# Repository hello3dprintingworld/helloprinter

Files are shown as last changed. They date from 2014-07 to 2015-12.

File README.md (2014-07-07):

helloprinter
============

Open Source Multi-Maker (3D printer, CNC, Laser cutter/engraver)

Based on the work of josef prusa, model prusa I3 link: https://github.com/josefprusa/Prusa3

Base model characteristics:

Build Size: 200mm x 200mm x 200mm
Resolution: Base nozzle has 3 diferent resolutions 0,2 , 0,3 and 0,5, if you choose the chess extruder you can go as high as 2mm, ideal for the bigger versions.
Z Resolution: Best achieved with a normal calbration 0,1mm , when well calibrated you can reach resolutions of 0,01mm
Materials: ABS, ABS-PC,ABS-Carborn, Glow In The Dark ABS and PLA, PLA, HIPS, Laywoo, Claywoo, Nylon, PVA and others
Speed: Up to 100mm/s (tested with 2000mm/s set up and worked)
Prepared for automatic bed levelling
Monkey Extruder - Super lightweight Dual extruder ( motors with half the weight of a nema 17) with the capability of separating both nozzles up to half the bed lenght, making possible the print of 2 objects in diferent materials or colors at the same time saving 50% of the building time for not having to do the same path twice.
The filament is visible all the way to the nozzle, making easy to do mantaince and cleaning
Stainless Steel Structure - Needed for having enough weight to withstand the CNC function
Magnétic Sensors for precise home positionning
Ramps 1.4 and Arduino Mega 2650 - 5 motor drivers (dual Z Driver and Dual Extruder), 3 12v exits for FAN, BED and EXTRUDER combinations and support for 4 servos.
LCD with SD card reader for Autonomouse print
Print speed control during print
Marlin Firmware

Software recomended
Kisslicer or Slic3r and pronterface

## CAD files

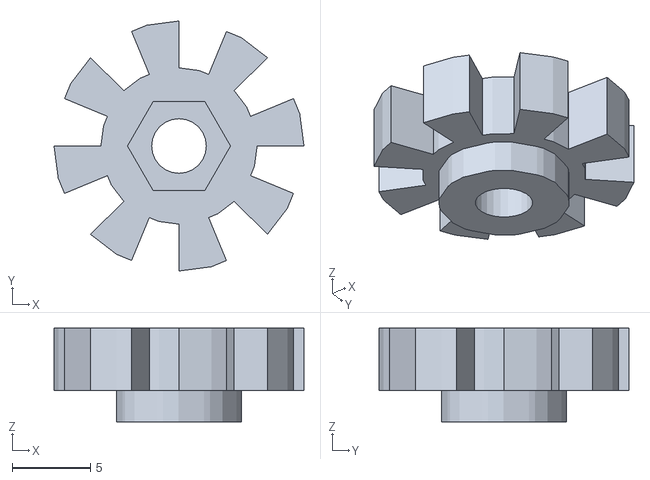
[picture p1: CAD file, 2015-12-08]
Bed/Bed Adjuster.stl
16.0 x 16.0 x 6.00

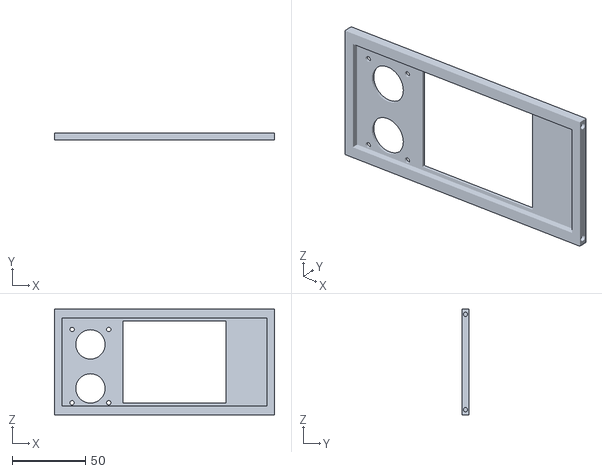
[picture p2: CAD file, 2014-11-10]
Controllers/RAMPS 14/RAMPS BACK 1X.stl
150.0 x 5.00 x 72.0

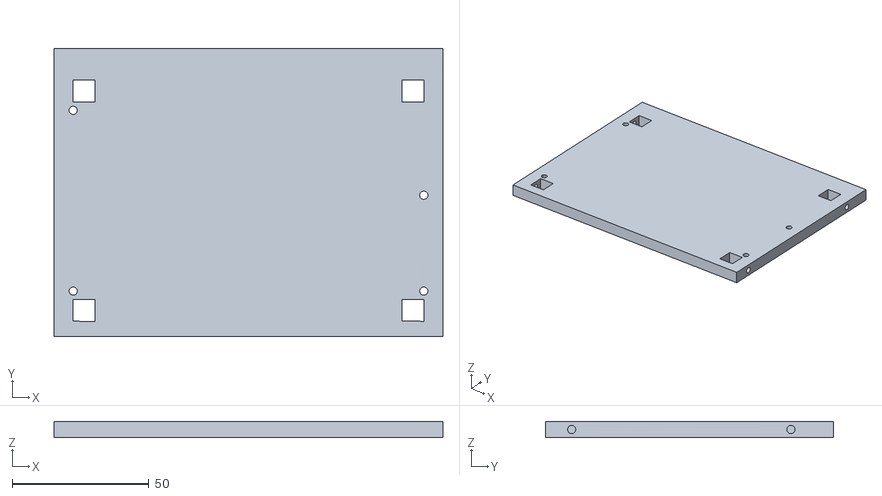
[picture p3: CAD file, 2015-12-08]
Controllers/RUMBA/Power Box Rumba BOT.stl
142.0 x 105.0 x 6.00

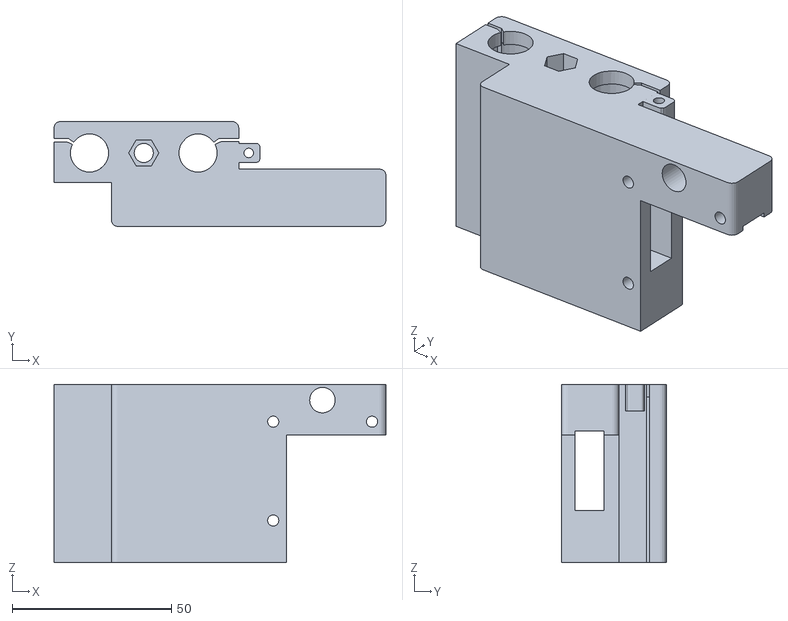
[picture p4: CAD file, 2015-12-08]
Eixo X/5mm/x axis motor.stl
104.2 x 32.9 x 56.0

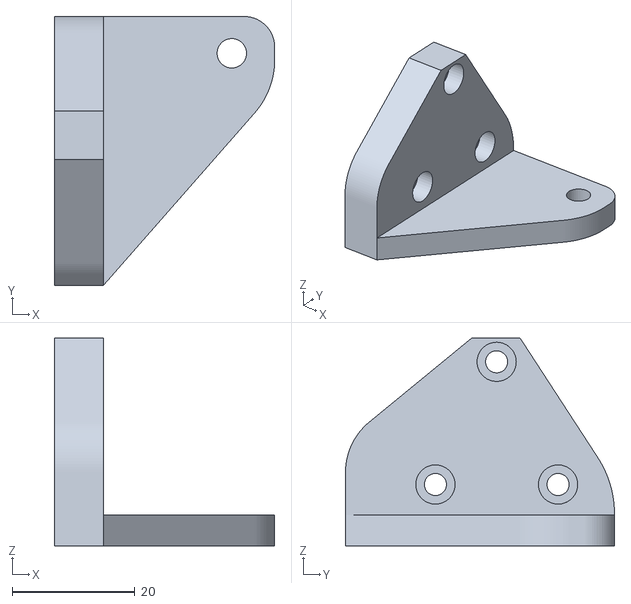
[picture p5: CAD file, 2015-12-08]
Eixo Y/Y idler 2.stl
35.9 x 43.9 x 33.9

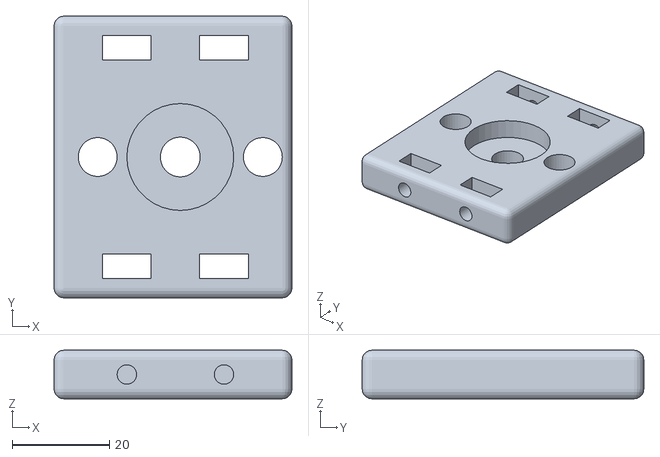
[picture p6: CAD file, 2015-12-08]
Eixo Z/Z Top x2.stl
49.0 x 58.0 x 10.0

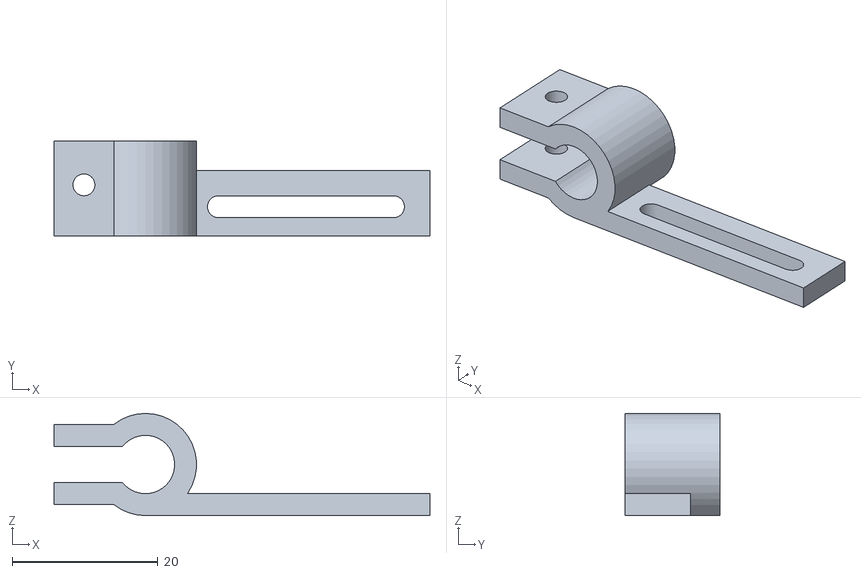
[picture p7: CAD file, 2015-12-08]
Endstops/Universal Endstop holder.STL
51.5 x 13.0 x 14.0

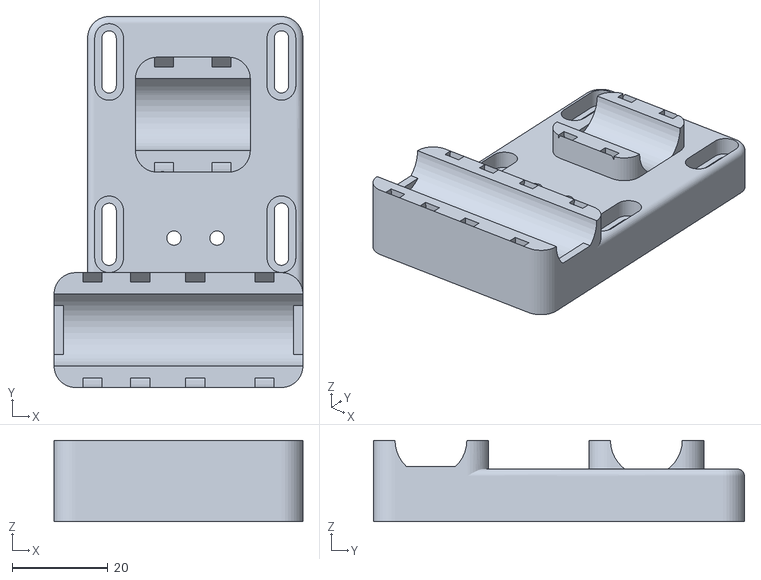
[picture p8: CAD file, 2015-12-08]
Extruder/Single Extruder for dual mirror parts/X Carriage.stl
52.0 x 77.5 x 17.0

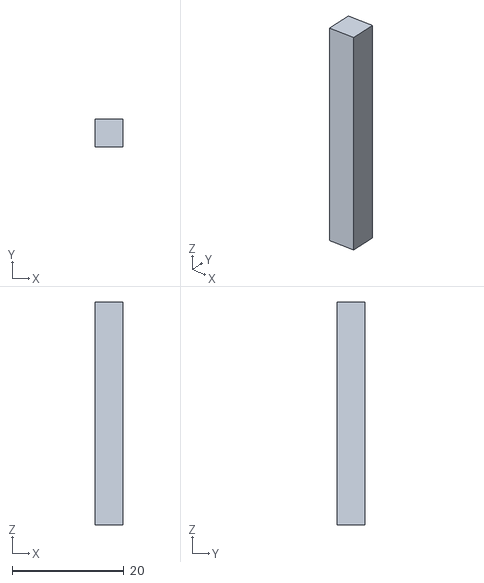
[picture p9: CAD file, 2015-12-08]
Impressão Teste/torre40mm.stl
5.00 x 5.00 x 40.0

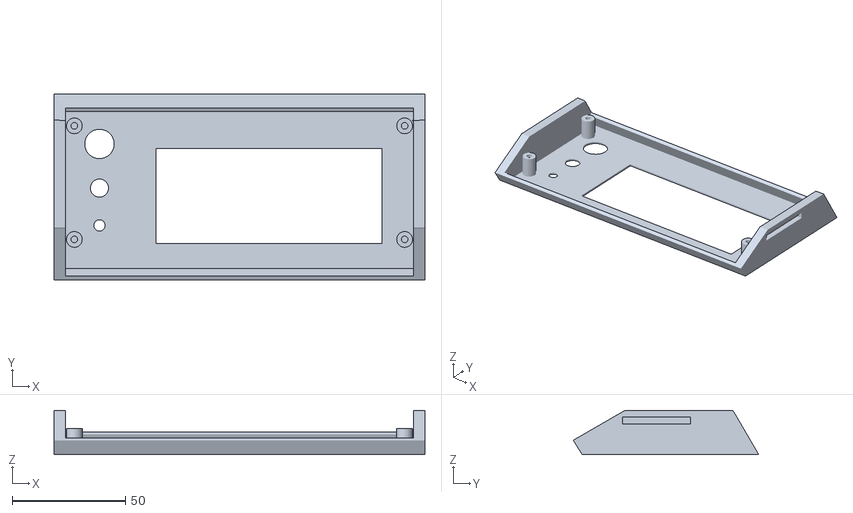
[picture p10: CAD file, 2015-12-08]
LCD/LCD_Mount.stl
164.0 x 82.0 x 19.5

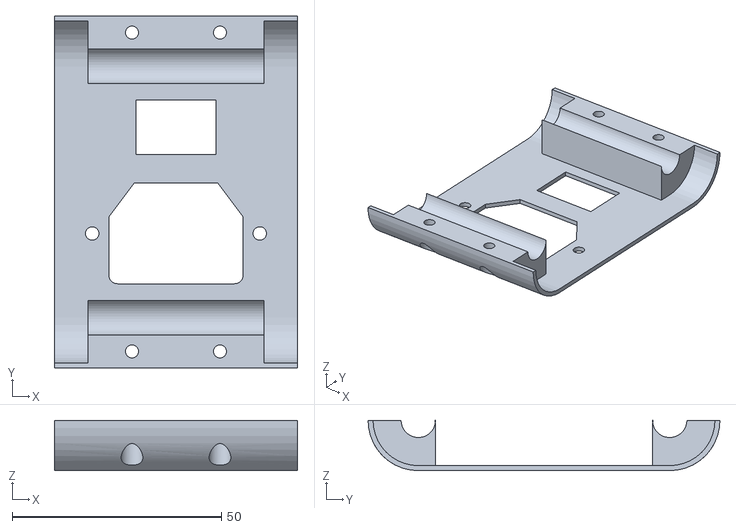
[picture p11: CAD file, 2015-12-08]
Plug and switch/Plug and switch front x1.STL
58.0 x 84.0 x 12.0

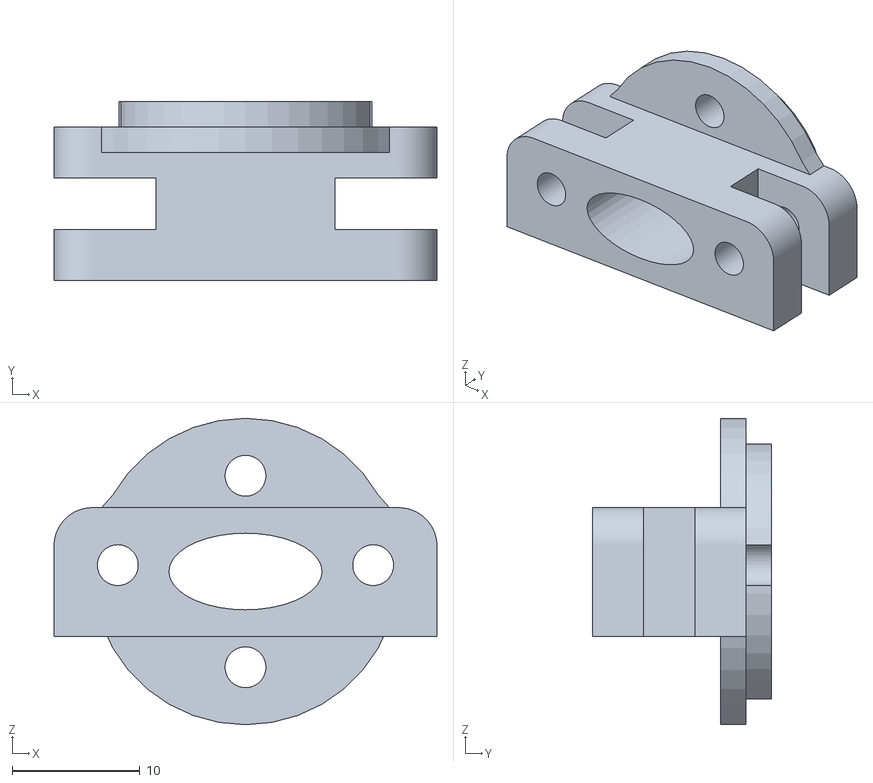
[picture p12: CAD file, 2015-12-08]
Power Supply/Frame cable connection front.stl
30.0 x 14.0 x 24.0

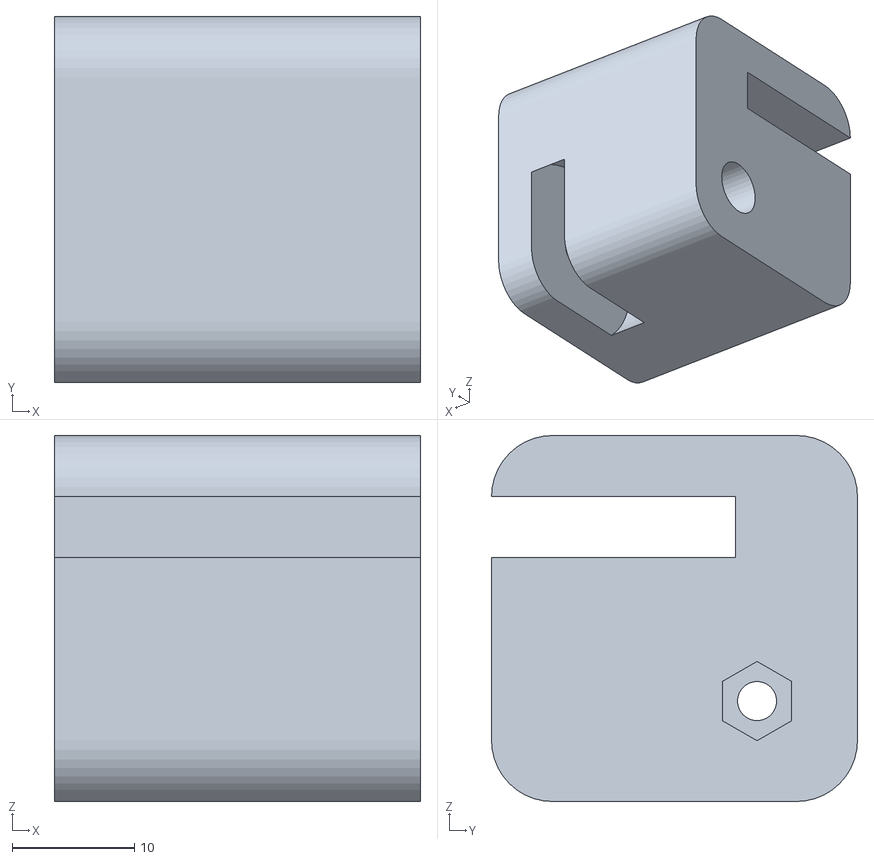
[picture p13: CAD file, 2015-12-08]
Reinforcement XL/Base.STL
30.0 x 30.0 x 30.0

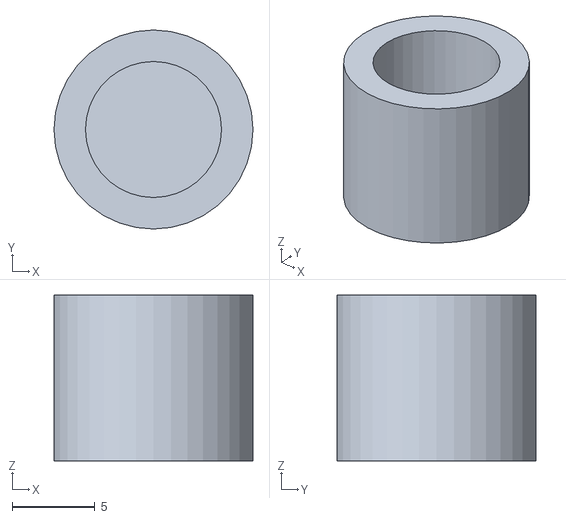
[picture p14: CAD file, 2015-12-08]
Spool Holder/Pointer.stl
12.0 x 12.0 x 10.0

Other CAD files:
Frame/frames.dwg
Bed/Bed Corner Extruder x2.stl
Controllers/RAMPS 14/RAMPS FRONT.stl
Controllers/RUMBA/Power Box Rumba Closed.stl
Bed/Bed corners normal x2.stl
Bed/i3_Adj_Y_Low_P_holder_02.stl
Controllers/RAMPS 14/RAMPS BOTTOM 1X.stl
Controllers/RAMPS 14/RAMPS LAT1.stl
Controllers/RAMPS 14/RAMPS LAT2.stl
Controllers/RAMPS 14/RAMPS TOP.stl
Controllers/RUMBA/LCD back.stl
Controllers/RUMBA/Power Box Rumba FRONT 2.stl
Controllers/RUMBA/Power Box Rumba LAT1.stl
Controllers/RUMBA/Power Box Rumba LAT2.stl
Controllers/RUMBA/Power Box Rumba Support.stl
Controllers/RUMBA/Power Box Rumba TOP.stl
Eixo X/5mm/x axis idler tensioner.stl
Eixo X/5mm/x axis idler.stl
Eixo Y/Y Idler 1.stl
Eixo Y/Y Motor.stl
Eixo Z/Z motor x2.stl
Endstops/endstop-holder-bottom x3.stl
Endstops/endstop-holder-top x3.stl
Extruder/Single Extruder for dual mirror parts/extruder - 1-50F.STL
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

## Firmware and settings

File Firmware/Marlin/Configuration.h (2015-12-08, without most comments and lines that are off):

#include <U8glib.h>
#define CONFIGURATION_H
#include "boards.h"
#define STRING_VERSION "1.0.2"
#define STRING_URL "reprap.org"
#define STRING_VERSION_CONFIG_H __DATE__ " " __TIME__ // build date and time
#define STRING_CONFIG_H_AUTHOR "(none, default config)" // Who made the changes.
#define STRING_SPLASH_LINE1 "v" STRING_VERSION // will be shown during bootup in line 1
#define SERIAL_PORT 0
#define BAUDRATE 250000
#define MOTHERBOARD 80
 #define CUSTOM_MENDEL_NAME "HelloPrinter"
#define EXTRUDERS 2
#define POWER_SUPPLY 1
#define TEMP_SENSOR_0 1
#define TEMP_SENSOR_1 1
#define TEMP_SENSOR_2 0
#define TEMP_SENSOR_3 0
#define TEMP_SENSOR_BED 1
#define MAX_REDUNDANT_TEMP_SENSOR_DIFF 10
#define TEMP_RESIDENCY_TIME 10  // (seconds)
#define TEMP_HYSTERESIS 3       // (degC) range of +/- temperatures considered "close" to the target one
#define TEMP_WINDOW     1       // (degC) Window around target to start the residency timer x degC early.
#define HEATER_0_MINTEMP 5
#define HEATER_1_MINTEMP 5
#define HEATER_2_MINTEMP 5
#define HEATER_3_MINTEMP 5
#define BED_MINTEMP 5
#define HEATER_0_MAXTEMP 275
#define HEATER_1_MAXTEMP 275
#define HEATER_2_MAXTEMP 275
#define HEATER_3_MAXTEMP 275
#define BED_MAXTEMP 150
#define PIDTEMP
#define BANG_MAX 255 // limits current to nozzle while in bang-bang mode; 255=full current
#define PID_MAX BANG_MAX // limits current to nozzle while PID is active (see PID_FUNCTIONAL_RANGE below); 255=full current
  #define PID_FUNCTIONAL_RANGE 10 // If the temperature difference between the target temperature and the actual temperature
  #define PID_INTEGRAL_DRIVE_MAX PID_MAX  //limit for the integral term
  #define K1 0.95 //smoothing factor within the PID
    #define  DEFAULT_Kp 22.2
    #define  DEFAULT_Ki 1.08
    #define  DEFAULT_Kd 114
#define MAX_BED_POWER 255 // limits duty cycle to bed; 255=full current
#define PREVENT_DANGEROUS_EXTRUDE
#define PREVENT_LENGTHY_EXTRUDE
#define EXTRUDE_MINTEMP 170
#define EXTRUDE_MAXLENGTH (X_MAX_LENGTH+Y_MAX_LENGTH) //prevent extrusion of very large distances.
#define THERMAL_RUNAWAY_PROTECTION_PERIOD 10 //in seconds
#define THERMAL_RUNAWAY_PROTECTION_HYSTERESIS 25 // in degree Celsius
#define THERMAL_RUNAWAY_PROTECTION_BED_PERIOD 10 //in seconds
#define THERMAL_RUNAWAY_PROTECTION_BED_HYSTERESIS 10 // in degree Celsius
#define ENDSTOPPULLUPS // Comment this out (using // at the start of the line) to disable the endstop pullup resistors
const bool X_MIN_ENDSTOP_INVERTING = false; // set to true to invert the logic of the endstop.
const bool Y_MIN_ENDSTOP_INVERTING = false; // set to true to invert the logic of the endstop.
const bool Z_MIN_ENDSTOP_INVERTING = false; // set to true to invert the logic of the endstop.
const bool X_MAX_ENDSTOP_INVERTING = false; // set to true to invert the logic of the endstop.
const bool Y_MAX_ENDSTOP_INVERTING = false; // set to true to invert the logic of the endstop.
const bool Z_MAX_ENDSTOP_INVERTING = false; // set to true to invert the logic of the endstop.
#define X_ENABLE_ON 0
#define Y_ENABLE_ON 0
#define Z_ENABLE_ON 0
#define E_ENABLE_ON 0 // For all extruders
#define DISABLE_X false
#define DISABLE_Y false
#define DISABLE_Z false
#define DISABLE_E false // For all extruders
#define DISABLE_INACTIVE_EXTRUDER true //disable only inactive extruders and keep active extruder enabled
#define INVERT_X_DIR false
#define INVERT_Y_DIR false
#define INVERT_Z_DIR false
#define INVERT_E0_DIR false
#define INVERT_E1_DIR false
#define INVERT_E2_DIR false
#define INVERT_E3_DIR false
#define X_HOME_DIR -1
#define Y_HOME_DIR -1
#define Z_HOME_DIR -1
#define min_software_endstops true // If true, axis won't move to coordinates less than HOME_POS.
#define max_software_endstops true  // If true, axis won't move to coordinates greater than the defined lengths below.
#define X_MIN_POS 0
#define Y_MIN_POS 0
#define Z_MIN_POS 0
#define X_MAX_POS 200
#define Y_MAX_POS 200
#define Z_MAX_POS 500
#define Z_PROBE_REPEATABILITY_TEST  // If not commented out, Z-Probe Repeatability test will be included if Auto Bed Leveling is Enabled.
#define NUM_AXIS 4 // The axis order in all axis related arrays is X, Y, Z, E
#define HOMING_FEEDRATE {50*60, 50*60, 4*60, 0}  // set the homing speeds (mm/min)
#define DEFAULT_AXIS_STEPS_PER_UNIT   {80,80,4000,1100}  // default steps per unit for Ultimaker
#define DEFAULT_MAX_FEEDRATE          {300, 300, 5, 45}    // (mm/sec)
#define DEFAULT_MAX_ACCELERATION      {1200,1200,100,300}    // X, Y, Z, E maximum start speed for accelerated moves. E default values are good for Skeinforge 40+, for older versions raise them a lot.
#define DEFAULT_ACCELERATION          250    // X, Y, Z and E acceleration in mm/s^2 for printing moves
#define DEFAULT_RETRACT_ACCELERATION  300   // E acceleration in mm/s^2 for retracts
#define DEFAULT_TRAVEL_ACCELERATION   1200    // X, Y, Z acceleration in mm/s^2 for travel (non printing) moves
#define DEFAULT_XYJERK                20.0    // (mm/sec)
#define DEFAULT_ZJERK                 0.4     // (mm/sec)
#define DEFAULT_EJERK                 2.0    // (mm/sec)
#define CUSTOM_M_CODES
#define PLA_PREHEAT_HOTEND_TEMP 180
#define PLA_PREHEAT_HPB_TEMP 70
#define PLA_PREHEAT_FAN_SPEED 0   // Insert Value between 0 and 255
#define ABS_PREHEAT_HOTEND_TEMP 240
#define ABS_PREHEAT_HPB_TEMP 110
#define ABS_PREHEAT_FAN_SPEED 0   // Insert Value between 0 and 255
#define LANGUAGE_INCLUDE GENERATE_LANGUAGE_INCLUDE(en)
  #define DISPLAY_CHARSET_HD44780_JAPAN        // this is the most common hardware
#define REPRAP_DISCOUNT_SMART_CONTROLLER
#define SOFT_PWM_SCALE 0
#define FILAMENT_SENSOR_EXTRUDER_NUM	0  //The number of the extruder that has the filament sensor (0,1,2)
#define MEASUREMENT_DELAY_CM			14  //measurement delay in cm.  This is the distance from filament sensor to middle of barrel
#define DEFAULT_NOMINAL_FILAMENT_DIA  3.0  //Enter the diameter (in mm) of the filament generally used (3.0 mm or 1.75 mm) - this is then used in the slicer software.  Used for sensor reading validation
#define MEASURED_UPPER_LIMIT          3.30  //upper limit factor used for sensor reading validation in mm
#define MEASURED_LOWER_LIMIT          1.90  //lower limit factor for sensor reading validation in mm
#define MAX_MEASUREMENT_DELAY			20  //delay buffer size in bytes (1 byte = 1cm)- limits maximum measurement delay allowable (must be larger than MEASUREMENT_DELAY_CM  and lower number saves RAM)
#define DEFAULT_MEASURED_FILAMENT_DIA  DEFAULT_NOMINAL_FILAMENT_DIA  //set measured to nominal initially
#include "Configuration_adv.h"
#include "thermistortables.h"

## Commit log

2014-08-12 UPDATE 08/14
    All extruders added
    [Bowden Paste Extruder top.stl, Bowden Paste Extruder.stl, SlidingC.stl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]
2014-08-28 Monkey Upgrade
    Upgraded the dimensions of the frame to support the monkey extruded.
    Redesigned superprinter to withstand bigger changes with smaller
    interviniences
    [frames produção.dwg, frames.dwg]
2014-08-29 Nema 17 compatible extruder
    We noticed that our 1/50 motor is too slow when extruding with
    resolution of 1mm and 2mm. For that we recomend you to use a faster
    motor as the nema 17. We design it so you just need to change the motors
    and not the full extruder. Use an electrical wire connector near the
    extruder to quick change it. All process can be done under 5min,
2014-10-13 Improved X axis parts
    Hi, we redesigned the x-axis parts so it could withstand more tension.
    We also improved the way the tensioner works, reducing the metal prants
    and making it much stronger.
    We use now two smooth rods to force the threaded rod to straitten if it
    has a small bend.
    [x axis idler 5mm Triagle Guide.stl, x axis idler 5mm tensioner Triagle Guide.stl, x axis idler 5mm.stl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]
2014-10-13 Improved Z axis
    Second part of the tension improvement. This parts allow the use of dual
    smooth rods so you have a bether Z move
    [apoio inferior Z 1.stl, apoio inferior Z 1Triple Grip.stl, apoio superior Z 1 Triple Grip.stl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]
2014-10-20 Extruder upgrade for Filaflex
    In our original extruder design we left some open spaces for you to see
    if and were the cloghs could happen.
    Unfortunelly that gaps are a problem when you use filaflex.
    We intruduced in ths version a PTFE guide that you can adjust to have 0
    gaps but still have space for you to track any problem.
    [extruder 2 PTFE GUIDE.stl, extruder 2.stl, extruder PTFE GUIDE.stl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]
2014-10-21 More Space for belts
    The inicial idler we design was small and the belt was touching the
    inner walls, we corrected this part so you don't need to sand it for a
    smoother move
    [x axis idler 5mm tensioner Triagle Guide.stl, x axis idler.stl, x axis motor.stl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]
2014-10-24 Remaned files and PSU
    Hi, we remaned all files with the quantities you need to print. We also
    added the power supply holder, we are designing a fan channel to avoid
    the bed. It will be avaiable very soon!
    [Bed Protection 1.stl, Bed Protection 2.stl, Power Supply holder x4.stl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]
2014-11-12 Rumba box final version
    [Power Box Rumba SUPPORT x2.stl]
2015-12-08 2015 Version
    2016 will be a 90% metal version. Development on its way
    [Apoio Dremmel 2cm.stl, Base.STL, Bed Adjuster.stl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]
